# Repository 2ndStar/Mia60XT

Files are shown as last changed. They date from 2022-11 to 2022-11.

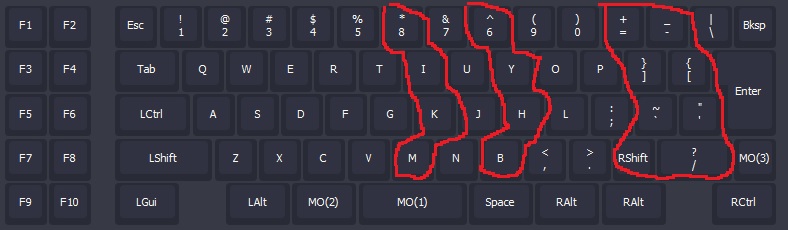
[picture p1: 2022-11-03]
PCB/Mia60XT/Firmware/rip.jpg

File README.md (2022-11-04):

# Mia60XT
This repository has the production files for the Mia60XT keyboard. It is a 60% (Fixed JIS Layout) + XT Column with Topre switches.
It has all the necessary files for one to create a copy for personal use.

# Terms of Use
Please refer to the LICENSE.md file in this repository for the terms of use. The purpose of sharing the design is so others may create their own copy of the keyboard if they wish while also preventing the commercial re-use of the design.

##  Disclaimer
- **PCB Files**: 
  - Not perfect! It works but needs to be bandaid fixed with Vial. I have no desire to fix the wiring issue but you're welcome to tinker with my rendition or make your own PCB.
  - I have absolutely no knowledge on how EC PCBs work. It is an (almost) 1 for 1 copy of [Cipulot's EC60](https://github.com/Cipulot/EC60). 
  - I do not take credit for the creation of the PCB.
  - All credits go to [Cipulot](https://github.com/Cipulot) for making the EC60 open source.

## PCB
### Note
- The project was initialy named **Faen** and the layout was to be 65% + XT. Ignore the naming of the PCB files.
- The Layout is fixed
The layout is fixed
proto

## Case
### Parts
- The case is a simple 2 parts (Top + bottom) and an accent piece
case
### Plate
- **Thickness**: 1.2mm
- **Material**: Metal - Something that can be tapped
  - I used Mild Steel because it's cheap on SendCutSend
- Self-tapped using a M2 tap head
  - SendCutSend also offers tapping service but might not for 1.2mm Mild Steel
- **Plate screws**:
  - x34 8mm M2 
  - Screw directly from backside of PCB and into the plate
### Mounting Style
- Gummy O-ring under the plate
  - Size: Large (70-75%)
  - Hardness: W/E you want
  - Source: [Mech.Land](https://mech.land/) or [Graveshift](https://graveshift.com/)
- Thin foam strip underside of Top Case
  - Prevents metal-metal contact between plate and underside of top case
  - McMaster Part: [1488N601](https://www.mcmaster.com/1488N601/)
oring
### Hardware
- Case Screws:
  - x8 8mm M2.5 Socket Head
- Accent Screws:
  - x2 5mm M2.5 Flat head
- Daughterboard Screws:
  - x4 4mm M2 
- Feet:
  - Source: [Keebio](https://keeb.io/collections/diy-parts/products/skuf-silicone-rubber-keyboard-feet)
### Daughterboard 
- Source: [Hineybush](https://hineybush.com/)

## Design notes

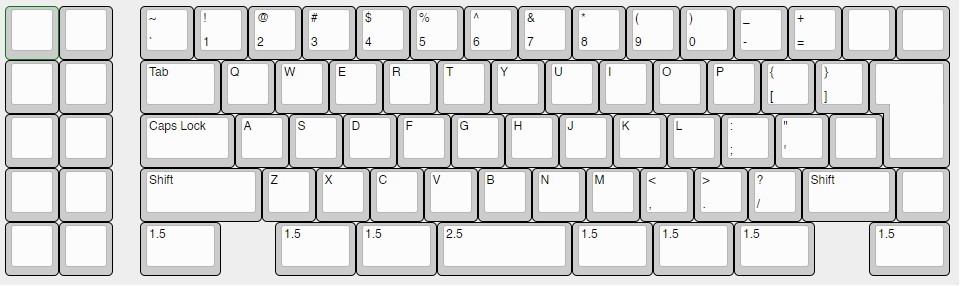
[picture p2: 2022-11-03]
Images/Mia60XTLayout.jpg

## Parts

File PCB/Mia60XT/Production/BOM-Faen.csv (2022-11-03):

Comment | Designator | Footprint | LCSC
1k | R28 | R_0402_1005Metric | C11702
STM32F401CBUx | U1 | QFN-48-1EP_7x7mm_P0.5mm_EP5.6x5.6mm | C118825
OPA350 | U5 | SOIC-8_3.9x4.9mm_P1.27mm | C13388
JST | J1 | JST-SR-4 | C145956
220p | C12 | C_0402_1005Metric | C1530
4.7u | C1 | C_0402_1005Metric | C23733
100 | R2, R3, R6, R7, R8 | R_0402_1005Metric | C25076
100k | R9, R12, R13, R14, R15, R16, R17, R18, R19, R20, R21, R22, R23, R24, R25, R26, R27, R29 | R_0402_1005Metric | C25741
10k | R1, R10, R11 | R_0402_1005Metric | C25744
5.1k | R4, R5 | R_0402_1005Metric | C25905
PRTR5V0U2X | D1 | SOT-143 | C2827688
TYPE-C-31-M-12 | J2 | HRO_TYPE-C-31-M-12 | C165948
100n | C2, C3, C4, C5, C6, C10, C11, C13 | C_0402_1005Metric | C307331
1u | C7, C8, C9 | C_0402_1005Metric | C52923
XC6206PxxxMR | U2 | SOT-23 | C5446
74HC4051 | U3, U4 | TSSOP16 | C5645
500mA | F1 | Fuse_1206_3216Metric | C70076
8 MHz | Y1 | Resonator_SMD_Murata_CSTxExxV-3Pin_3.0x1.1mm | C907975

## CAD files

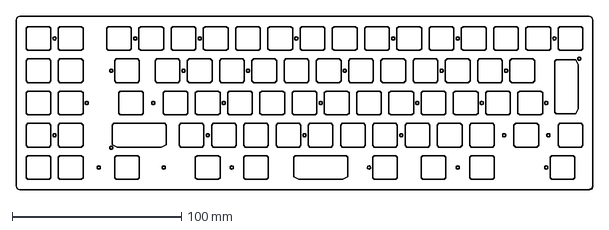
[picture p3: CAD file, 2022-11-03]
Case/faenPlateGummy.dxf
340.4 x 102.2 mm

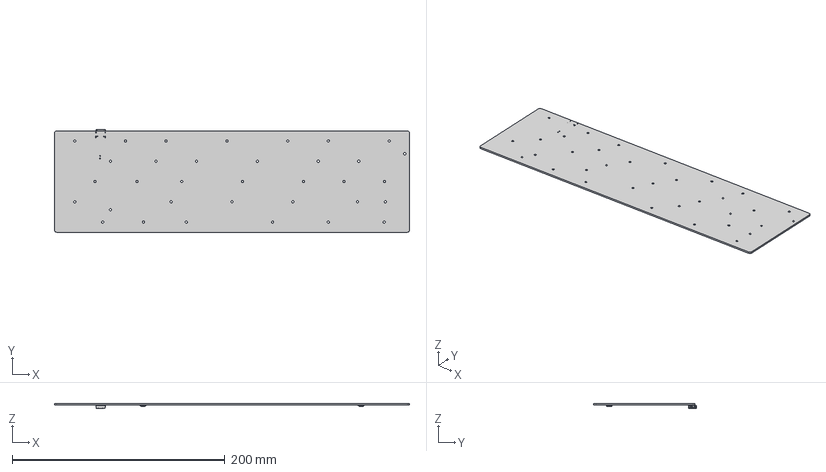
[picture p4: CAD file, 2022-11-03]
PCB/Mia60XT/Faen-PCB.step
333.4 x 96.3 x 4.95 mm
Faen65XT PCB

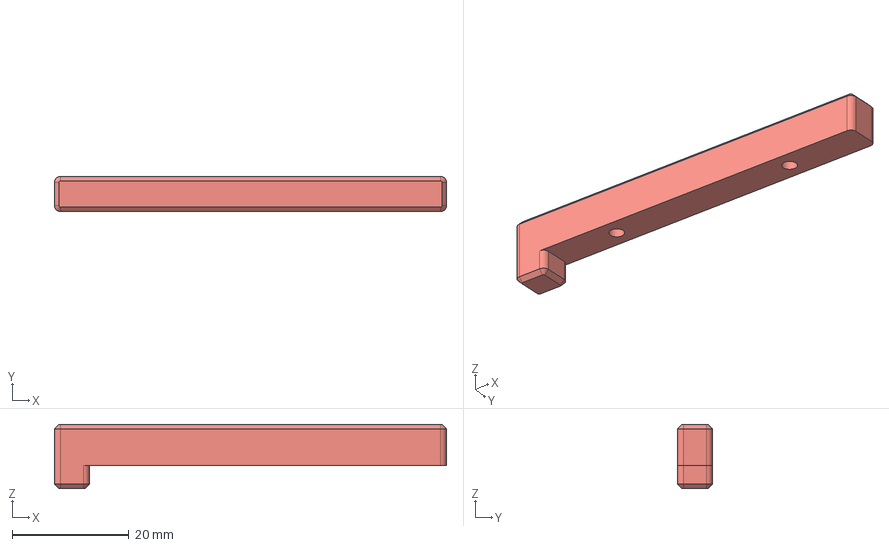
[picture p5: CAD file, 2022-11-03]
Case/MiaAccent.step
67.1 x 6.00 x 11.0 mm

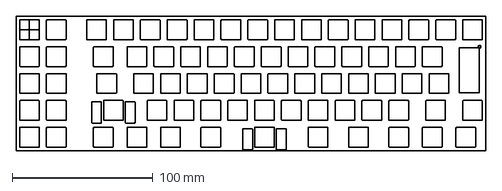
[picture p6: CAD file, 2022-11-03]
PCB/Mia60XT/plateguide1.dxf
333.4 x 95.2 mm

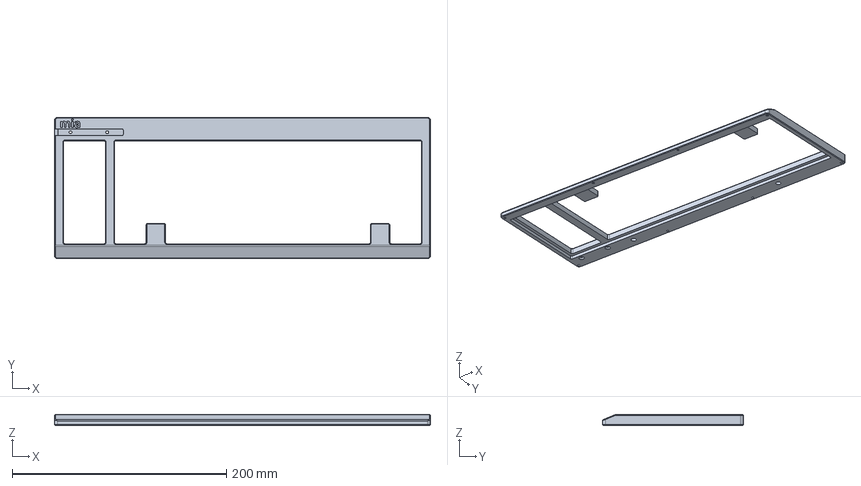
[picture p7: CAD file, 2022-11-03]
Case/MiaTopCase.step
351.3 x 132.2 x 10.0 mm

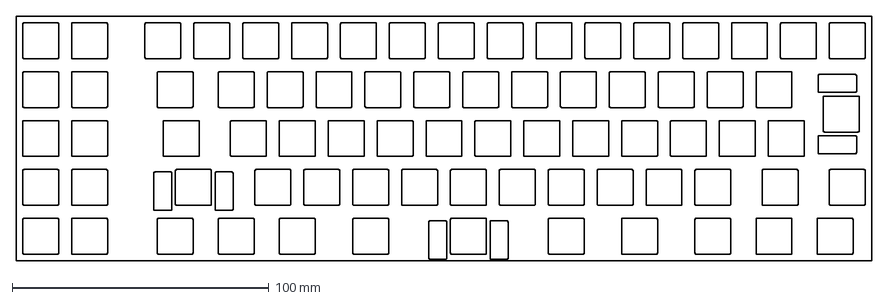
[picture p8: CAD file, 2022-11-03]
PCB/Mia60XT/plateguide.dxf
333.4 x 95.2 mm

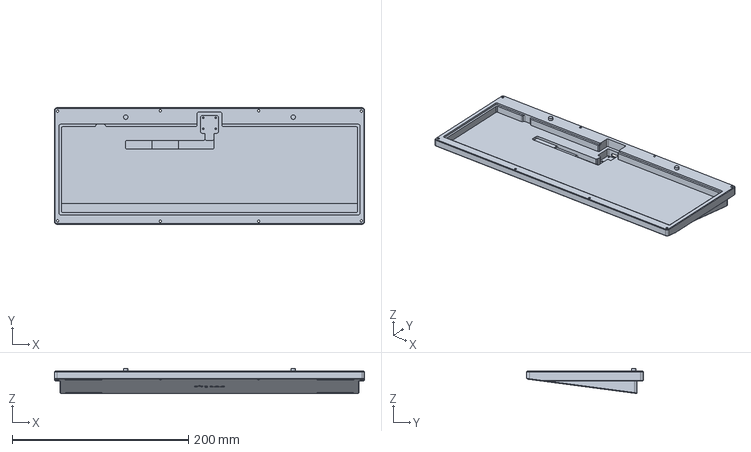
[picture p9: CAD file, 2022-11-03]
Case/MiaBottomCase.step
351.3 x 132.2 x 28.4 mm

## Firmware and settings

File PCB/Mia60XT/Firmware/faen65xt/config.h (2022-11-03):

/* Copyright 2022 jaydenta
 */

#pragma once

#include "config_common.h"

/* key matrix size */
#define MATRIX_ROWS 5
#define MATRIX_COLS 16

/* Custom matrix pins and port select array */
#define MATRIX_ROW_PINS \
    { A8, A9, B0, A7, B1 }
#define MATRIX_COL_CHANNELS \
    { 1, 0, 3, 2, 5, 4, 7, 6 }
#define MUX_SEL_PINS \
    { B6, B5, B4 }

/* Hardware peripherals pins */
#define APLEX_EN_PIN_0 B7
#define APLEX_EN_PIN_1 B3
#define DISCHARGE_PIN A6
#define ANALOG_PORT A3

/* COL2ROW, ROW2COL */
#define DIODE_DIRECTION COL2ROW

/* Debounce reduces chatter (unintended double-presses) - set 0 if debouncing is not needed */
//#define DEBOUNCE 5

/* Mechanical locking support. Use KC_LCAP, KC_LNUM or KC_LSCR instead in keymap */
#define LOCKING_SUPPORT_ENABLE

/* Locking resynchronize hack */
#define LOCKING_RESYNC_ENABLE

#define DEBUG_MATRIX_SCAN_RATE

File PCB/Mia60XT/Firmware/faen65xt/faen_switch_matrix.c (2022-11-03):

/* Copyright 2022 jaydenta
 */

#include "faen_switch_matrix.h"

#include "quantum.h"
#include "analog.h"
#include "atomic_util.h"
#include "print.h"

#define WAIT_DISCHARGE()
#define WAIT_CHARGE()

/* Pin and port array */
const uint32_t row_pins[]     = MATRIX_ROW_PINS;
const uint8_t  col_channels[] = MATRIX_COL_CHANNELS;
const uint32_t mux_sel_pins[] = MUX_SEL_PINS;

static ecsm_config_t config;
static uint16_t      ecsm_sw_value[MATRIX_ROWS][MATRIX_COLS];

static adc_mux adcMux;

static inline void discharge_capacitor(void) {
    writePinLow(DISCHARGE_PIN);
}
static inline void charge_capacitor(uint8_t row) {
    writePinHigh(DISCHARGE_PIN);
    writePinHigh(row_pins[row]);
}

static inline void clear_all_row_pins(void) {
    for (int row = 0; row < 6; row++) {
        writePinLow(row_pins[row]);
    }
}

static inline void init_mux_sel(void) {
    for (int idx = 0; idx < 3; idx++) {
        setPinOutput(mux_sel_pins[idx]);
    }
}

static inline void select_mux(uint8_t col) {
    uint8_t ch = col_channels[col];
    writePin(mux_sel_pins[0], ch & 1);
    writePin(mux_sel_pins[1], ch & 2);
    writePin(mux_sel_pins[2], ch & 4);
}

static inline void init_row(void) {
    for (int idx = 0; idx < 5; idx++) {
        setPinOutput(row_pins[idx]);
        writePinLow(row_pins[idx]);
    }
}

/* Initialize the peripherals pins */
int ecsm_init(ecsm_config_t const* const ecsm_config) {
    // Save config
    config = *ecsm_config;

    palSetLineMode(ANALOG_PORT, PAL_MODE_INPUT_ANALOG);
    adcMux = pinToMux(ANALOG_PORT);

    // Initialize discharge pin as discharge mode
    writePinLow(DISCHARGE_PIN);
    setPinOutputOpenDrain(DISCHARGE_PIN);

    // Initialize drive lines
    init_row();

    // Initialize multiplexer select pin
    init_mux_sel();

    // Enable AMUX
    setPinOutput(APLEX_EN_PIN_0);
    writePinLow(APLEX_EN_PIN_0);
    setPinOutput(APLEX_EN_PIN_1);
    writePinLow(APLEX_EN_PIN_1);

    return 0;
}

// Read the capacitive sensor value
static uint16_t ecsm_readkey_raw(uint8_t channel, uint8_t row, uint8_t col) {
    uint16_t sw_value = 0;

    // Select the multiplexer
    if (channel == 0) {
        writePinHigh(APLEX_EN_PIN_0);
        select_mux(col);
        writePinLow(APLEX_EN_PIN_0);
    } else {
        writePinHigh(APLEX_EN_PIN_1);
        select_mux(col);
        writePinLow(APLEX_EN_PIN_1);
    }

    // Set strobe pins to low state
    writePinLow(row_pins[row]);

    ATOMIC_BLOCK_FORCEON {
        // Set the row pin to high state and have capacitor charge
        charge_capacitor(row);

        WAIT_CHARGE();
        sw_value = adc_read(adcMux);
    }

    // Discharge peak hold capacitor
    discharge_capacitor();
    WAIT_DISCHARGE();

    return sw_value;
}

// Update press/release state of key at (row, col)
static bool ecsm_update_key(matrix_row_t* current_row, uint8_t row, uint8_t col, uint16_t sw_value) {
    bool current_state = (*current_row >> col) & 1;

    // press to release
    if (current_state && sw_value < config.low_threshold_matrix[row][col]) {
        *current_row &= ~(1 << col);
        return true;
    }

    // release to press
    if ((!current_state) && sw_value > config.high_threshold_matrix[row][col]) {
        *current_row |= (1 << col);
        return true;
    }

    return false;
}

// Scan key values and update matrix state
bool ecsm_matrix_scan(matrix_row_t current_matrix[]) {
    bool updated = false;

    // Disable AMUX of channel 1
    writePinHigh(APLEX_EN_PIN_1);
    for (int col = 0; col < sizeof(col_channels); col++) {
        for (int row = 0; row < 5; row++) {
            ecsm_sw_value[row][col] = ecsm_readkey_raw(0, row, col);
            updated |= ecsm_update_key(&current_matrix[row], row, col, ecsm_sw_value[row][col]);
        }
    }

    // Disable AMUX of channel 1
    writePinHigh(APLEX_EN_PIN_0);
    for (int col = 0; col < sizeof(col_channels); col++) {
        for (int row = 0; row < 5; row++) {
            ecsm_sw_value[row][col + 8] = ecsm_readkey_raw(1, row, col);
            updated |= ecsm_update_key(&current_matrix[row], row, col + 8, ecsm_sw_value[row][col + 8]);
        }
    }
    return updated;
}

// Debug print key values
void ecsm_print_matrix(void) {
    for (int row = 0; row < 5; row++) {
        for (int col = 0; col < 16; col++) {
            uprintf("%4d", ecsm_sw_value[row][col]);
            if (col < 16) {
                print(",");
            }
        }
        print("\n");
    }
    print("\n");
}

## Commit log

2022-11-03 add PCB and Case files
    [BOM-Faen.csv, Faen-PCB.step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]
2022-11-03 Add plate file
    [faenPlateGummy.dxf]
